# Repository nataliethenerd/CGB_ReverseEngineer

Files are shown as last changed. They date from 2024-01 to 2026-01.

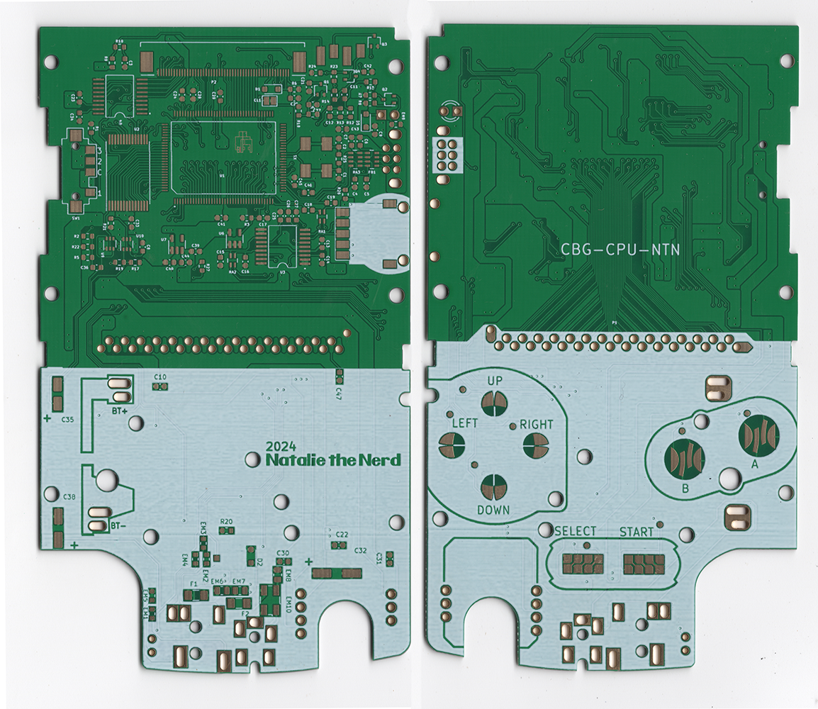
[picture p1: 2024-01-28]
Image_20240127_0002.png

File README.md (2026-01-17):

# CGB Reverse Engineer
I scanned, sanded and redrew the CGB schematics using a CGB-CPU-04 board. The original schematic was used as a refrence for values.

Scans of the original PCB can be found on my [Wiki](https://wiki.nataliethenerd.com/gameboy/gameboycolor) along with other Game Boy references. 

Share the Wiki with your friends, it encourages me share more


# PCBWay order link

If you would like to support me, meaning I can release more of these kinds of things please consider ordering through my PCBWay links.

ORDER AT 1mm and ENIG 

| Silkscreen | No silkscreen |
|---| -----|
| silk | nosilk |
| [PCBWay Link](https://www.pcbway.com/project/shareproject/Replacement_Game_Boy_Color_PCB_76fc2991.html) | [PCBWay Link](https://www.pcbway.com/project/shareproject/Replacement_Game_Boy_Color_PCB_8a4feba1.html) |

[interactive BOM](https://nataliethenerd.github.io/cgb.html)

While I have made multiple boards using the schematics, there may be some inaccuracies with values and layout. I am a hobbyist, not an electrical engineer at Nintendo.

PLEASE read the licence. If you are an a$$ - you are are actively responsible for people in the Game Boy community never wanting to share things. You are the selfish one

### Updates

Jan 26: added gerbers

### Follow me!
[Twitter](https://twitter.com/natalie_thenerd)

[Instagram](https://www.instagram.com/natalie.thenerd/)

[Modded Gameboy Club](https://moddedgameboy.club/) - a club dedicated to the modification of Game Boys, freely sharing resources
# License

 
NonCommercial — You may not use the material for commercial purposes.

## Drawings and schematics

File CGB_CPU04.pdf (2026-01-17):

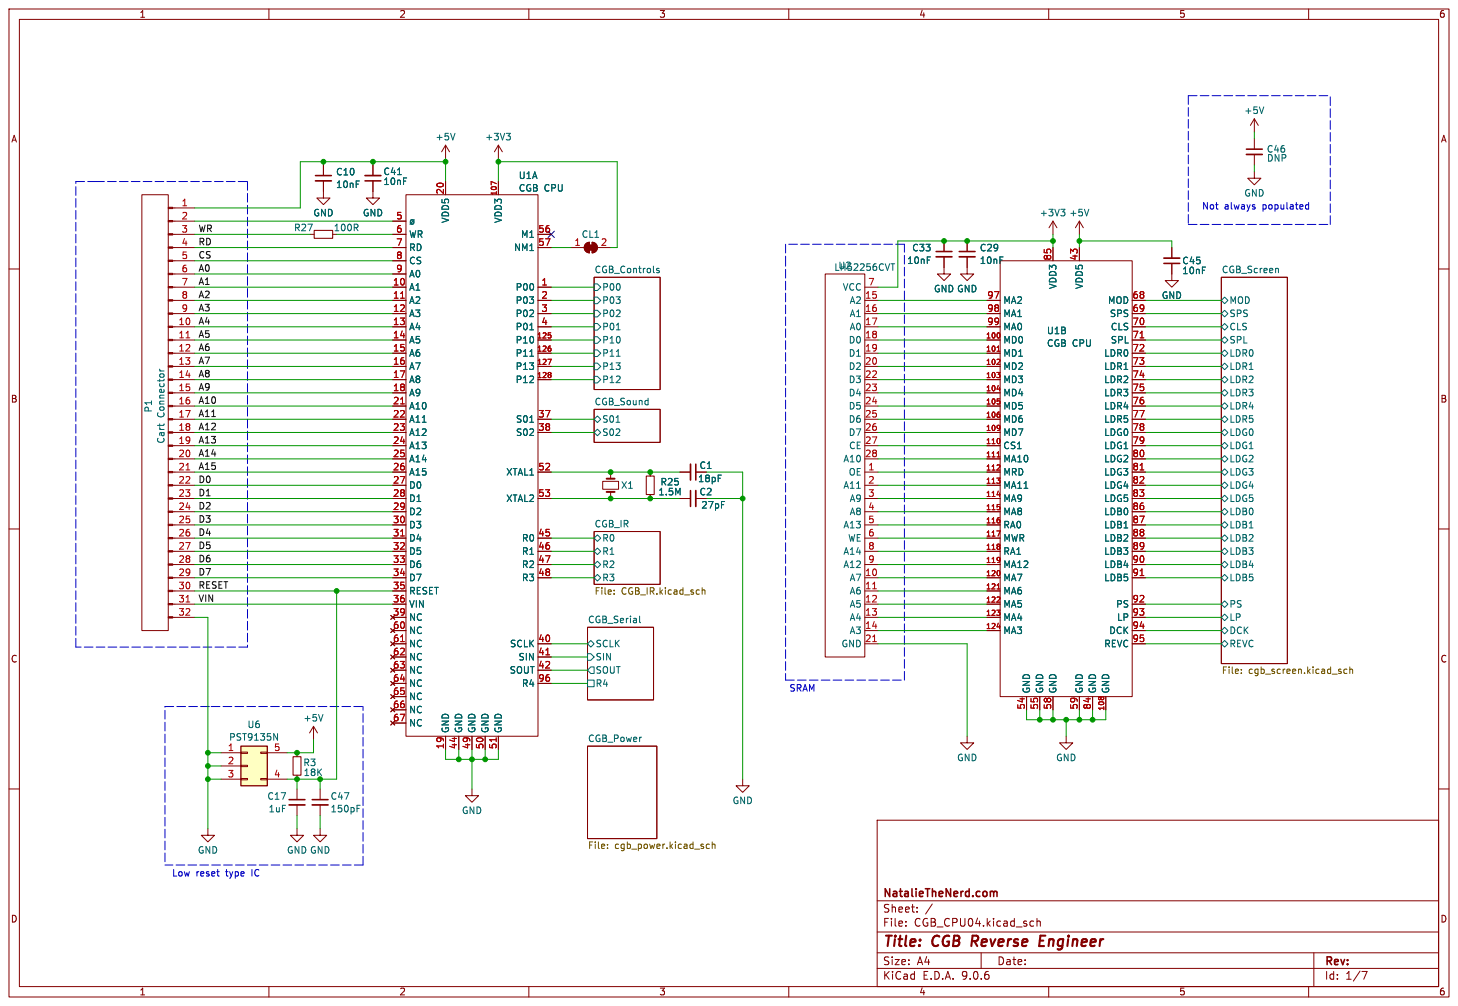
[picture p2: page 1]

Not always populated SRAM

LP 93 DCK 94 REVC 95 GND GND

Low reset type IC

Id: 1/7 Title: CGB Reverse Engineer File: CGB_CPU04.kicad_sch Sheet: / NatalieTheNerd.com

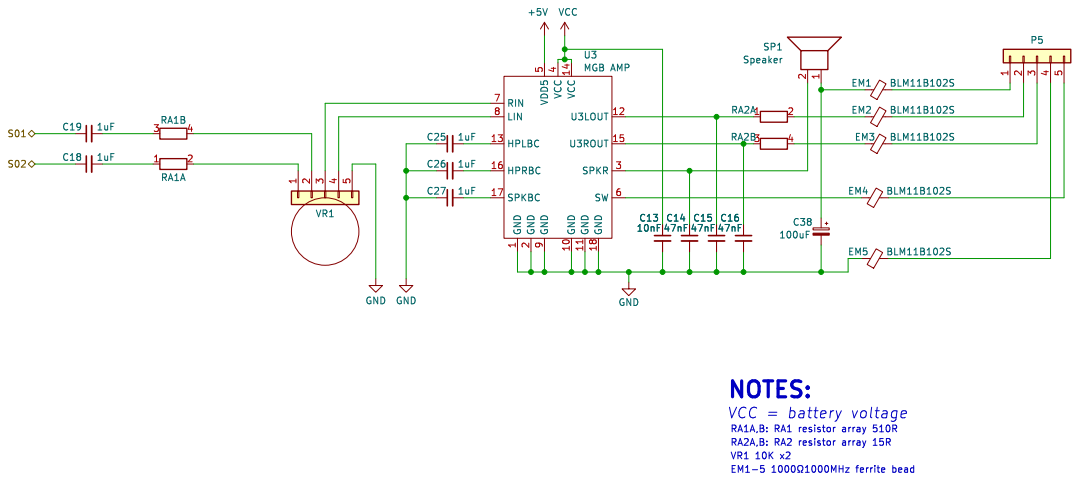
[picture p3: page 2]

4 VCC 14 GND 10 GND 11 GND 18 U3LOUT 12 U3ROUT 15 SPKR 3 SW 6 U3 MGB AMP

Id: 2/7 Title: CGB Reverse Engineer File: CGB_Sound.kicad_sch Sheet: /CGB_Sound/ NatalieTheNerd.com

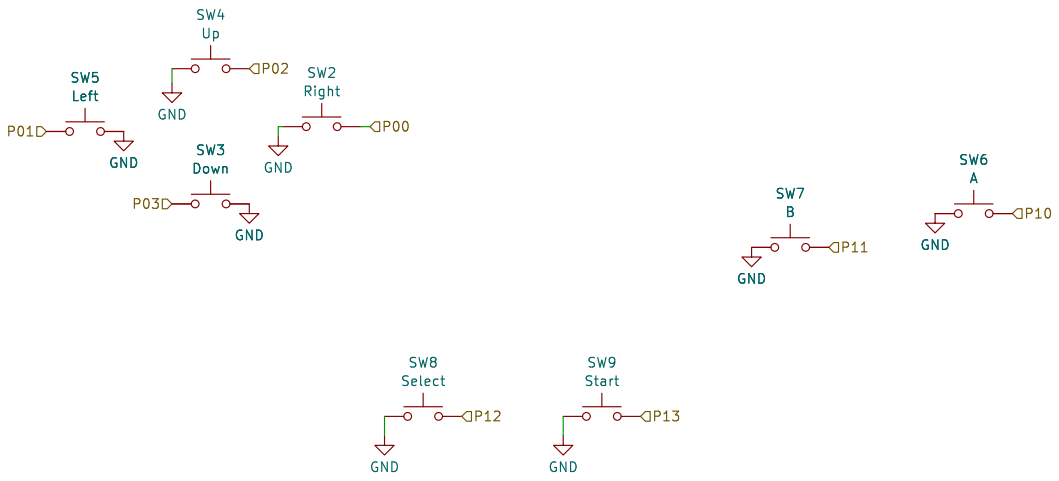
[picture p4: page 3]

Id: 3/7 Title: CGB Reverse Engineer File: CGB_Controls.kicad_sch Sheet: /CGB_Controls/ NatalieTheNerd.com

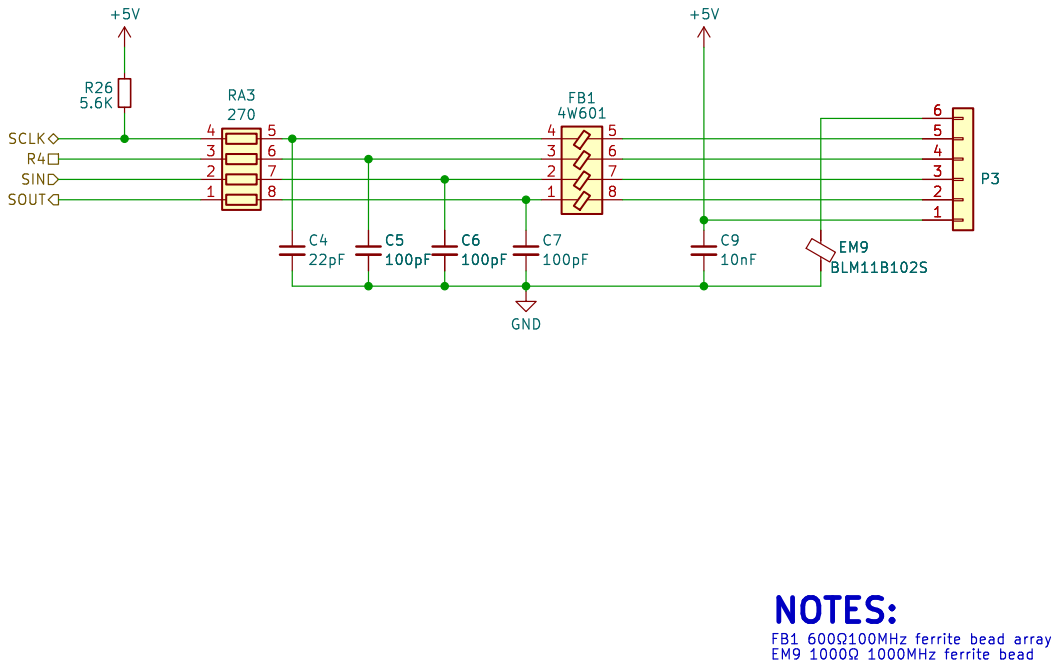
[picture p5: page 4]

FB1 þÿ600©100MHz ferrite bead array (https://github.com/nataliethenerd/CGB_ReverseEngineer/blob/main/datasheets/4W601.pdf) EM9 þÿ1000©1000MHz ferrite bead EM9 BLM11B102S

Id: 4/7 Title: CGB Reverse Engineer File: CGB_Serial.kicad_sch Sheet: /CGB_Serial/ NatalieTheNerd.com

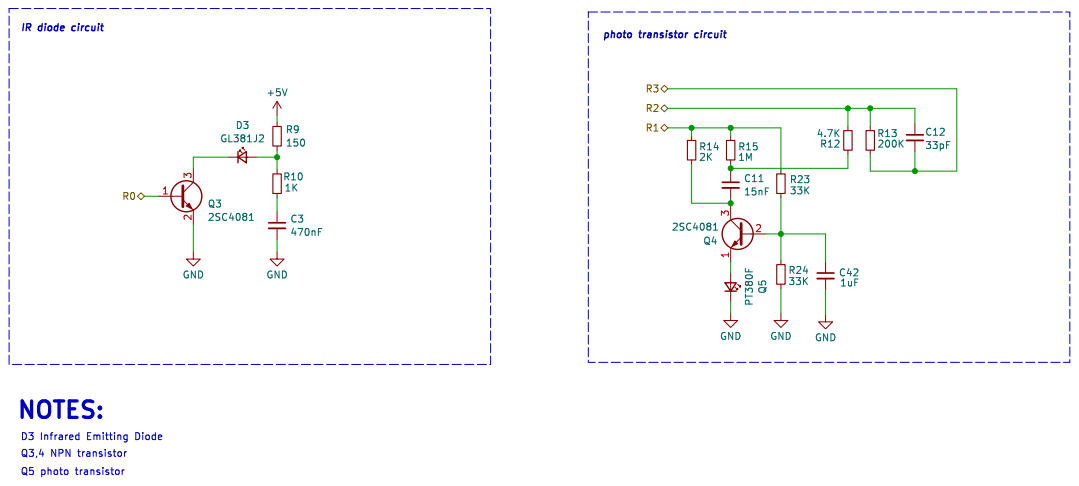
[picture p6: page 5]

Id: 5/7 Title: CGB Reverse Engineer File: CGB_IR.kicad_sch Sheet: /CGB_IR/ NatalieTheNerd.com

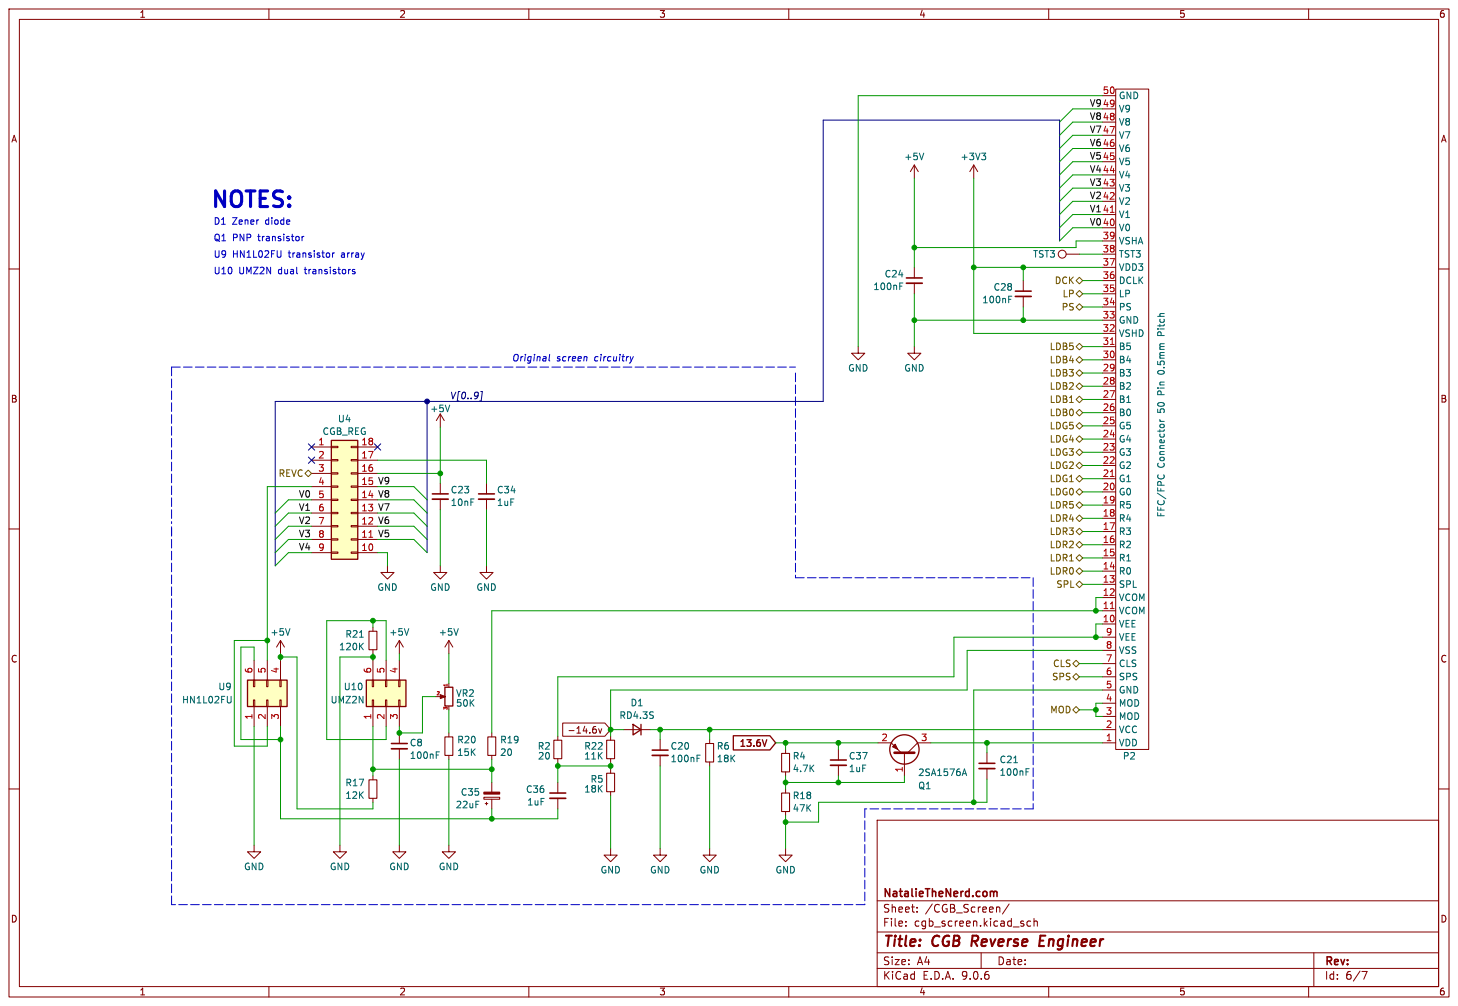
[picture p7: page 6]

Id: 6/7 Title: CGB Reverse Engineer File: cgb_screen.kicad_sch Sheet: /CGB_Screen/ NatalieTheNerd.com

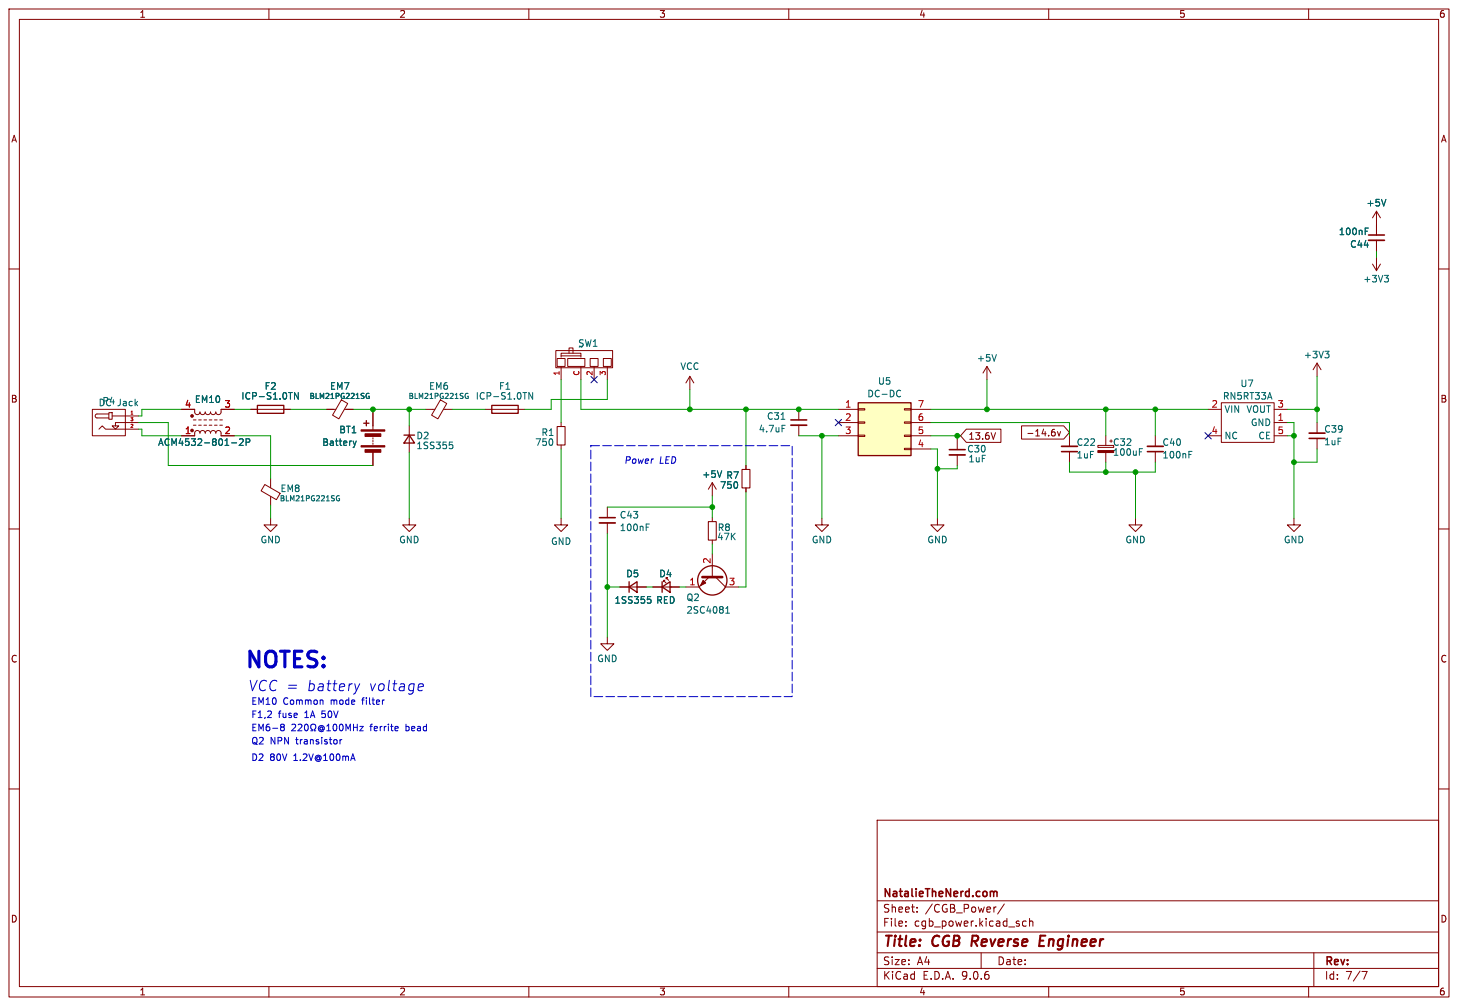
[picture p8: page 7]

Id: 7/7 Title: CGB Reverse Engineer File: cgb_power.kicad_sch Sheet: /CGB_Power/ NatalieTheNerd.com

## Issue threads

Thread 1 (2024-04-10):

CGB_IR.kicad_sch component Q4 has mixed the legs base and emitter.

giltesa, 2024-04-10:
Hello Natalie,

I checked your file CGB_IR.kicad_sch and I think the component **Q4** has mixed the legs **base** and **emitter**.

In your schematic the **base** is connected to **Q5** and the **emitter** to **R23**, however the Game Boy Color Service Manual and my game boy color mainboard have their **base** connected to **R23** and **emitter** to **Q5**.

Kind regards,
giltesa

nataliethenerd, 2024-05-01:
Working on fixing this, thank you Giltesa!

Closed 2024-07-14.

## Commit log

2024-01-26 kicad schematic
    [CGB_IR.kicad_sch, CGB_Serial.kicad_sch, CGB_Sound.kicad_sch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]
2024-07-14 fixed schematic, thx giltesa and darren
    the ir transistor was labelled wrong
    [CGB_IR.kicad_sch, CGB_Serial.kicad_sch, CGB_Sound.kicad_sch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]
2026-01-17 added gerbers
    [CGB_IR.kicad_sch, CGB_Serial.kicad_sch, CGB_Sound.kicad_sch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]

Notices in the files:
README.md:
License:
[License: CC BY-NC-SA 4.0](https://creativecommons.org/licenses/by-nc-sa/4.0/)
